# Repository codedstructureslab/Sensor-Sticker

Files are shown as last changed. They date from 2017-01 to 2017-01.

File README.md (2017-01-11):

# Sensor-Sticker

Minimal hardware for distributed sensing in aircraft, etc.

## Version

**Version 0:** 
* Minimal sensor size, irregular boards
* Ordered 2016-12-30

**Version 1:** 
* Constant sensor button size
* (TODO) Ensure that distance between connector edge and sensor centerpoint is 1.7 mm
* (TODO) Redo jtag pinout for Atmel ICE programmer
* Redo DSP310 Pinout to make assembly clearer

**Version 2:**
* ATSAMD11 Output?

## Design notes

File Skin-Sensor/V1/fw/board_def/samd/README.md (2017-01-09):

# Arduino Core for SAMD21 (E variant) CPU

This repository containts the source code and configuration files of the Arduino Core
for Atmel's SAMD21 (E variant) processor, which is used on the skin sensor boards.

## Installation on Arduino IDE

First, you should have Arduino > 1.6

To satisfy the dependencies, just open the "Boards Manager" and install the package called:

"Arduino SAMD Boards (32-bit ARM Cortex-M0+)"

Then drag this folder (`board_def`) to the `hardware` folder in the sketch directory of your Arduino installation (or make a symlink). Restart Arduino and you should see the board `Sensor-Sticker V1` listed. Select this board and upload the sketch `Skin-Sensor-AIAA`.

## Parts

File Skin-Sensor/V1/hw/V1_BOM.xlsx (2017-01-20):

Reference Designator | Quantity | Description/Value | Manufacturer Part Number (MPN)
C1,C2,C5,C6,C24,C25 | 6 | 0402 Cer Cap 1uF | C1005X5R1V105K050BC
C7,C8 | 2 | 0402 Cer Cap 22pF | CBR04C220F5GAC
C4,C9 | 2 | Wm1389 Plug (10) | 5034801000
C3,C20,C21,C23,C28,C40,C41 | 7 | 0402 Cer Cap 100nF | GRM155R71C104KA88J
C19 | 1 | 0402 Cer Cap 10uF | CL05A106MP8NUB8
C22 | 1 | 0402 Cer Cap 10nF | GRM155R71H103KA88D
C26,C27 | 2 | 0402 Cer Cap 0.47uF | C1005X5R1E474K050BB
R1 | 1 | 0402 Res 330 | RC0402JR-07330RL
R2,R3,R8,R9,R10,R11,R12,R13 | 8 | 0402 Res 10k | RC0402JR-0710KL
R14 | 1 | 0402 Res 100k | RC0402JR-07100KL
D1 | 1 | 0402 LED | LNJ247W82RA
D2 | 1 | RGB LED Common Cathode | XZM2CRKM2DGFBB45SCCB
C15,C30,C31,C32,C33,C37,C38,C39 | 8 | WM1386 Plug | 5034800400
C16,C17,C18 | 3 | WM1387 Plug | 5034800600
SW1,SW2 | 2 | Switch | TL3700AF100QG
J1 | 1 | 5x2 Header JTAG 0.05" | 20021121-00010C4LF
U1 | 1 | ADP7102 3.3V Reg | ADP7102ACPZ-3.3-R7
U2 | 1 | ATSAMD21E18A uP | ATSAMD21E18A-MFT
U3 | 1 | USBMICRO | 10104110-0001LF
U4 | 1 | LSM9DS1 IMU | LSM9DS1TR
U5 | 1 | LP5521YQ LED Driver | LP5521YQ/NOPB
U6,U7 | 2 | DPS310 Pressure Sensor | DPS310XTSA1
X1 | 1 | 32.768kHz Crystal | ABS06-32.768KHZ-1-T

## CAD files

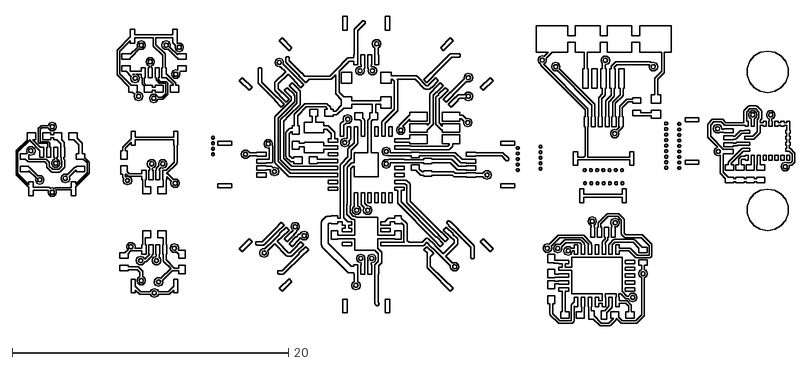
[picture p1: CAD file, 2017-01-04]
Skin-Sensor/V1/hw/CAD/DXF_OUT/Skin_Sensor_Modular_Min_BoardSize-F.Cu.dxf
56.4 x 22.4

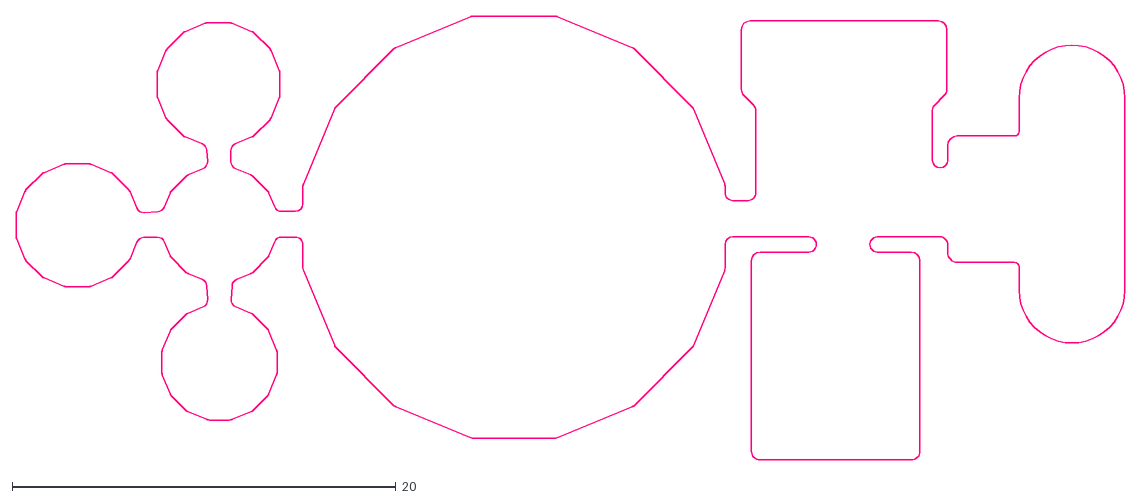
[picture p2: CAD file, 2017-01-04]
Skin-Sensor/V1/hw/CAD/Skin_Sensor_Modular_Board_Edge_Buttons.dxf
57.8 x 23.1

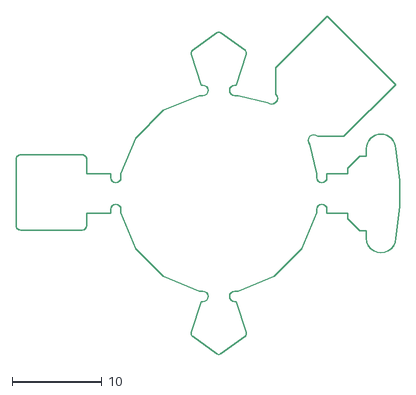
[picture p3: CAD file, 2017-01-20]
Skin-Sensor/V1/hw/DXF_OUT/Skin_Sensor_Outline_V1.dxf
42.8 x 37.8

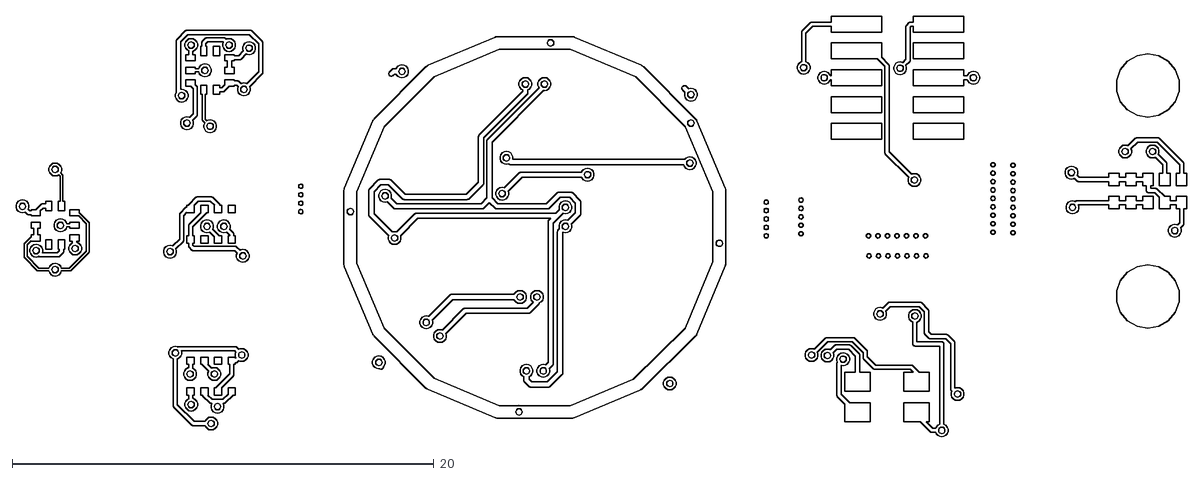
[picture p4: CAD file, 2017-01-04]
Skin-Sensor/V1/hw/CAD/DXF_OUT/Skin_Sensor_Modular_Min_BoardSize-B.Cu.dxf
55.5 x 20.0

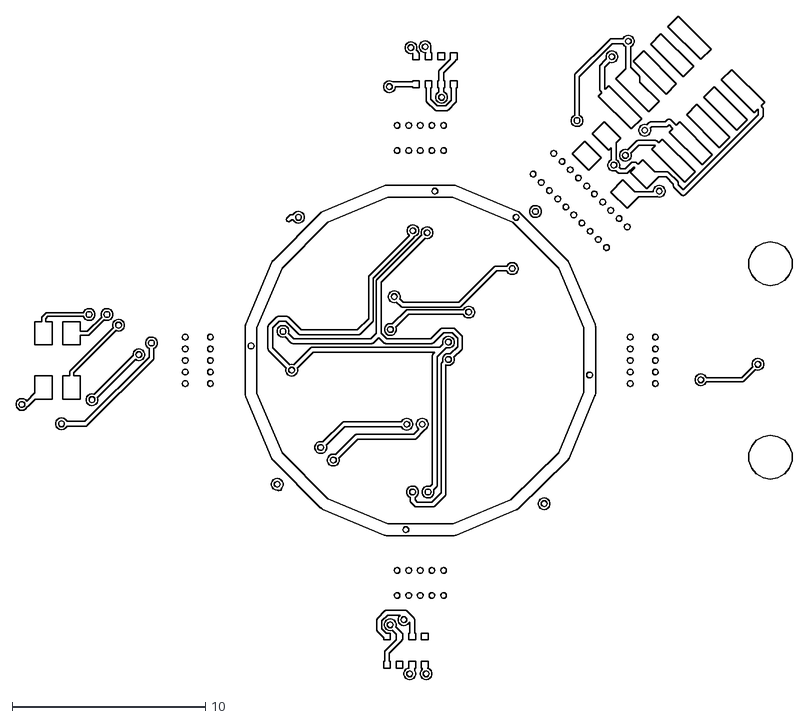
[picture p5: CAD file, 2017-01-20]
Skin-Sensor/V1/hw/DXF_OUT/Skin-Sensor-V1-B.Cu.dxf
40.1 x 34.3

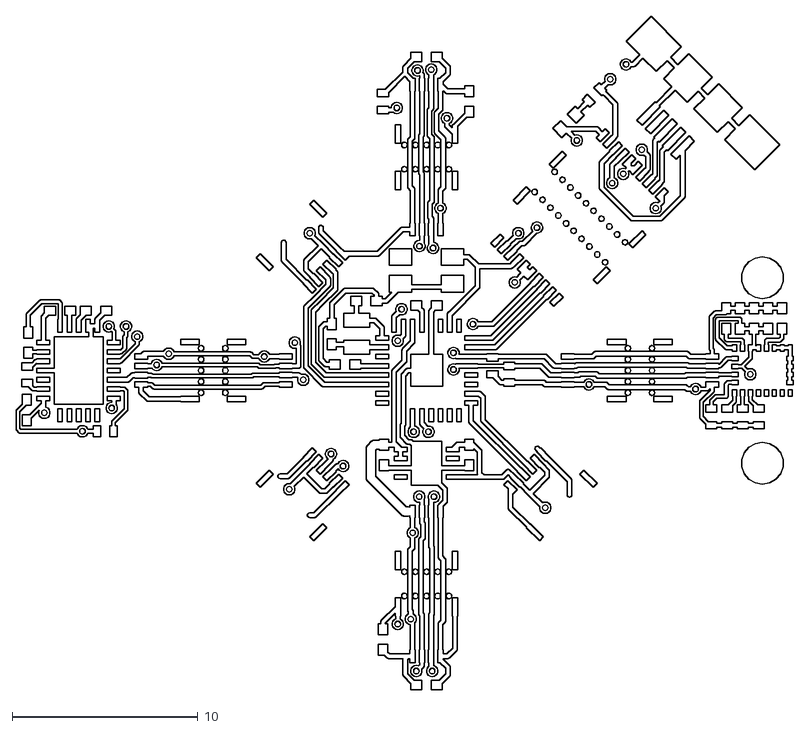
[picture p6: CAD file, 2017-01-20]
Skin-Sensor/V1/hw/DXF_OUT/Skin-Sensor-V1-F.Cu.dxf
41.9 x 36.3

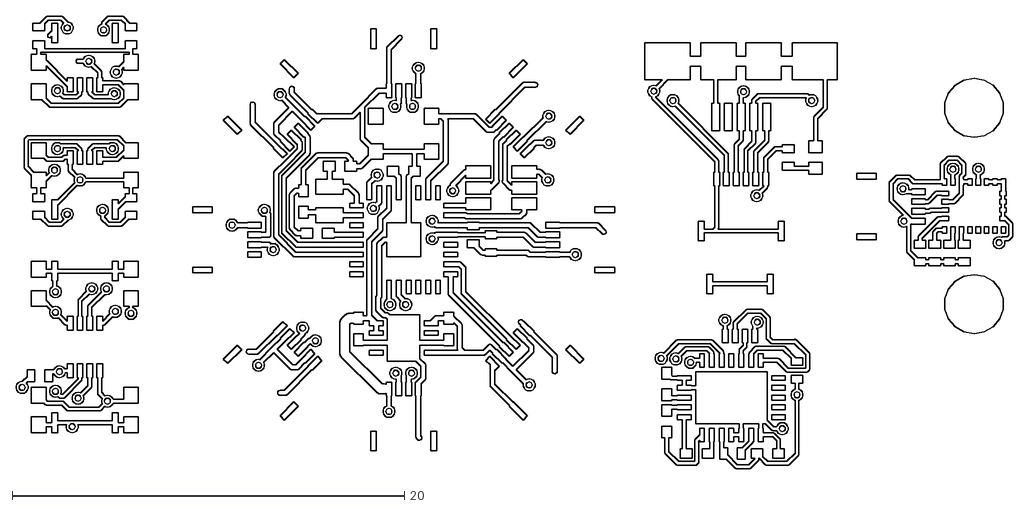
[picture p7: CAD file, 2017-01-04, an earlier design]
Skin-Sensor/V0/CAD/DXF_OUT/Skin_Sensor_Modular-F.Cu.dxf
50.8 x 23.1

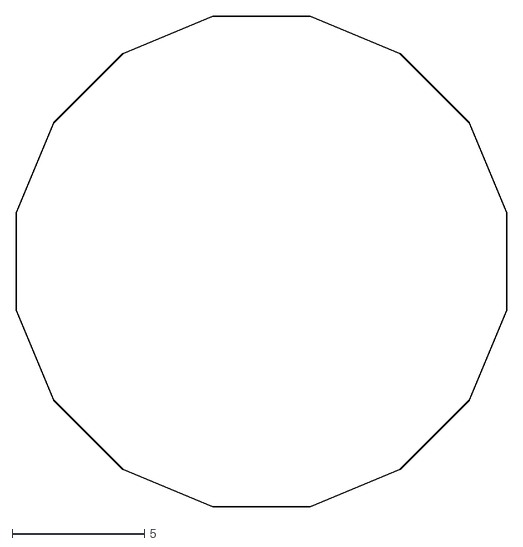
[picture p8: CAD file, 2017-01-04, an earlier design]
Skin-Sensor/V0/CAD/DXF_OUT/SSM_CopperBorderInner.dxf
18.5 x 18.5

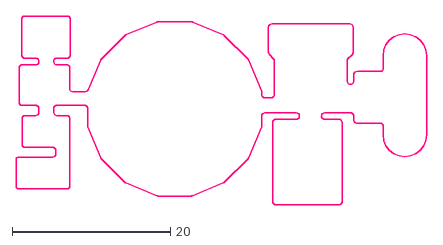
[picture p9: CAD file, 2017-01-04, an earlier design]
Skin-Sensor/V0/CAD/Skin_Sensor_Modular_Board_Edge.dxf
51.8 x 23.9

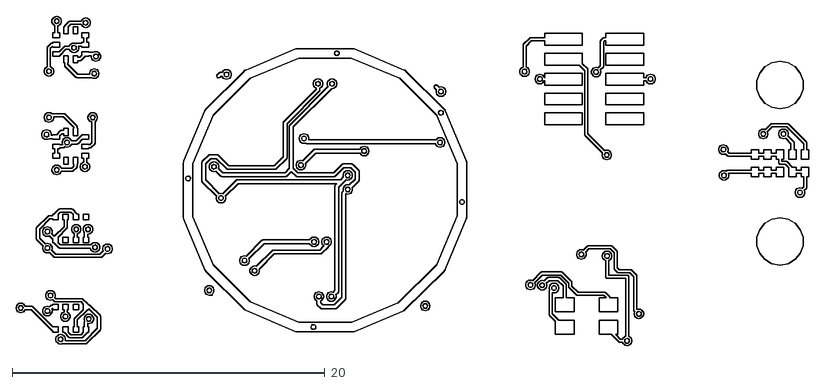
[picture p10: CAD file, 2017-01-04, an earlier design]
Skin-Sensor/V0/CAD/DXF_OUT/Skin_Sensor_Modular-B.Cu.dxf
50.7 x 21.0

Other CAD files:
Skin-Sensor/V0/CAD/Skin_Sensor_Modular_explanatory_drawing.dwg
Skin-Sensor/V0/CAD/DXF_OUT/Skin_Sensor_Modular-B.SilkS.dxf
Skin-Sensor/V0/CAD/DXF_OUT/Skin_Sensor_Modular-F.SilkS.dxf
Skin-Sensor/V0/CAD/Skin_Sensor_Modular_Board_Edge.3dm
Skin-Sensor/V1/hw/CAD/DXF_OUT/Skin_Sensor_Modular_Min_BoardSize-B.SilkS.dxf
Skin-Sensor/V1/hw/CAD/DXF_OUT/Skin_Sensor_Modular_Min_BoardSize-F.SilkS.dxf

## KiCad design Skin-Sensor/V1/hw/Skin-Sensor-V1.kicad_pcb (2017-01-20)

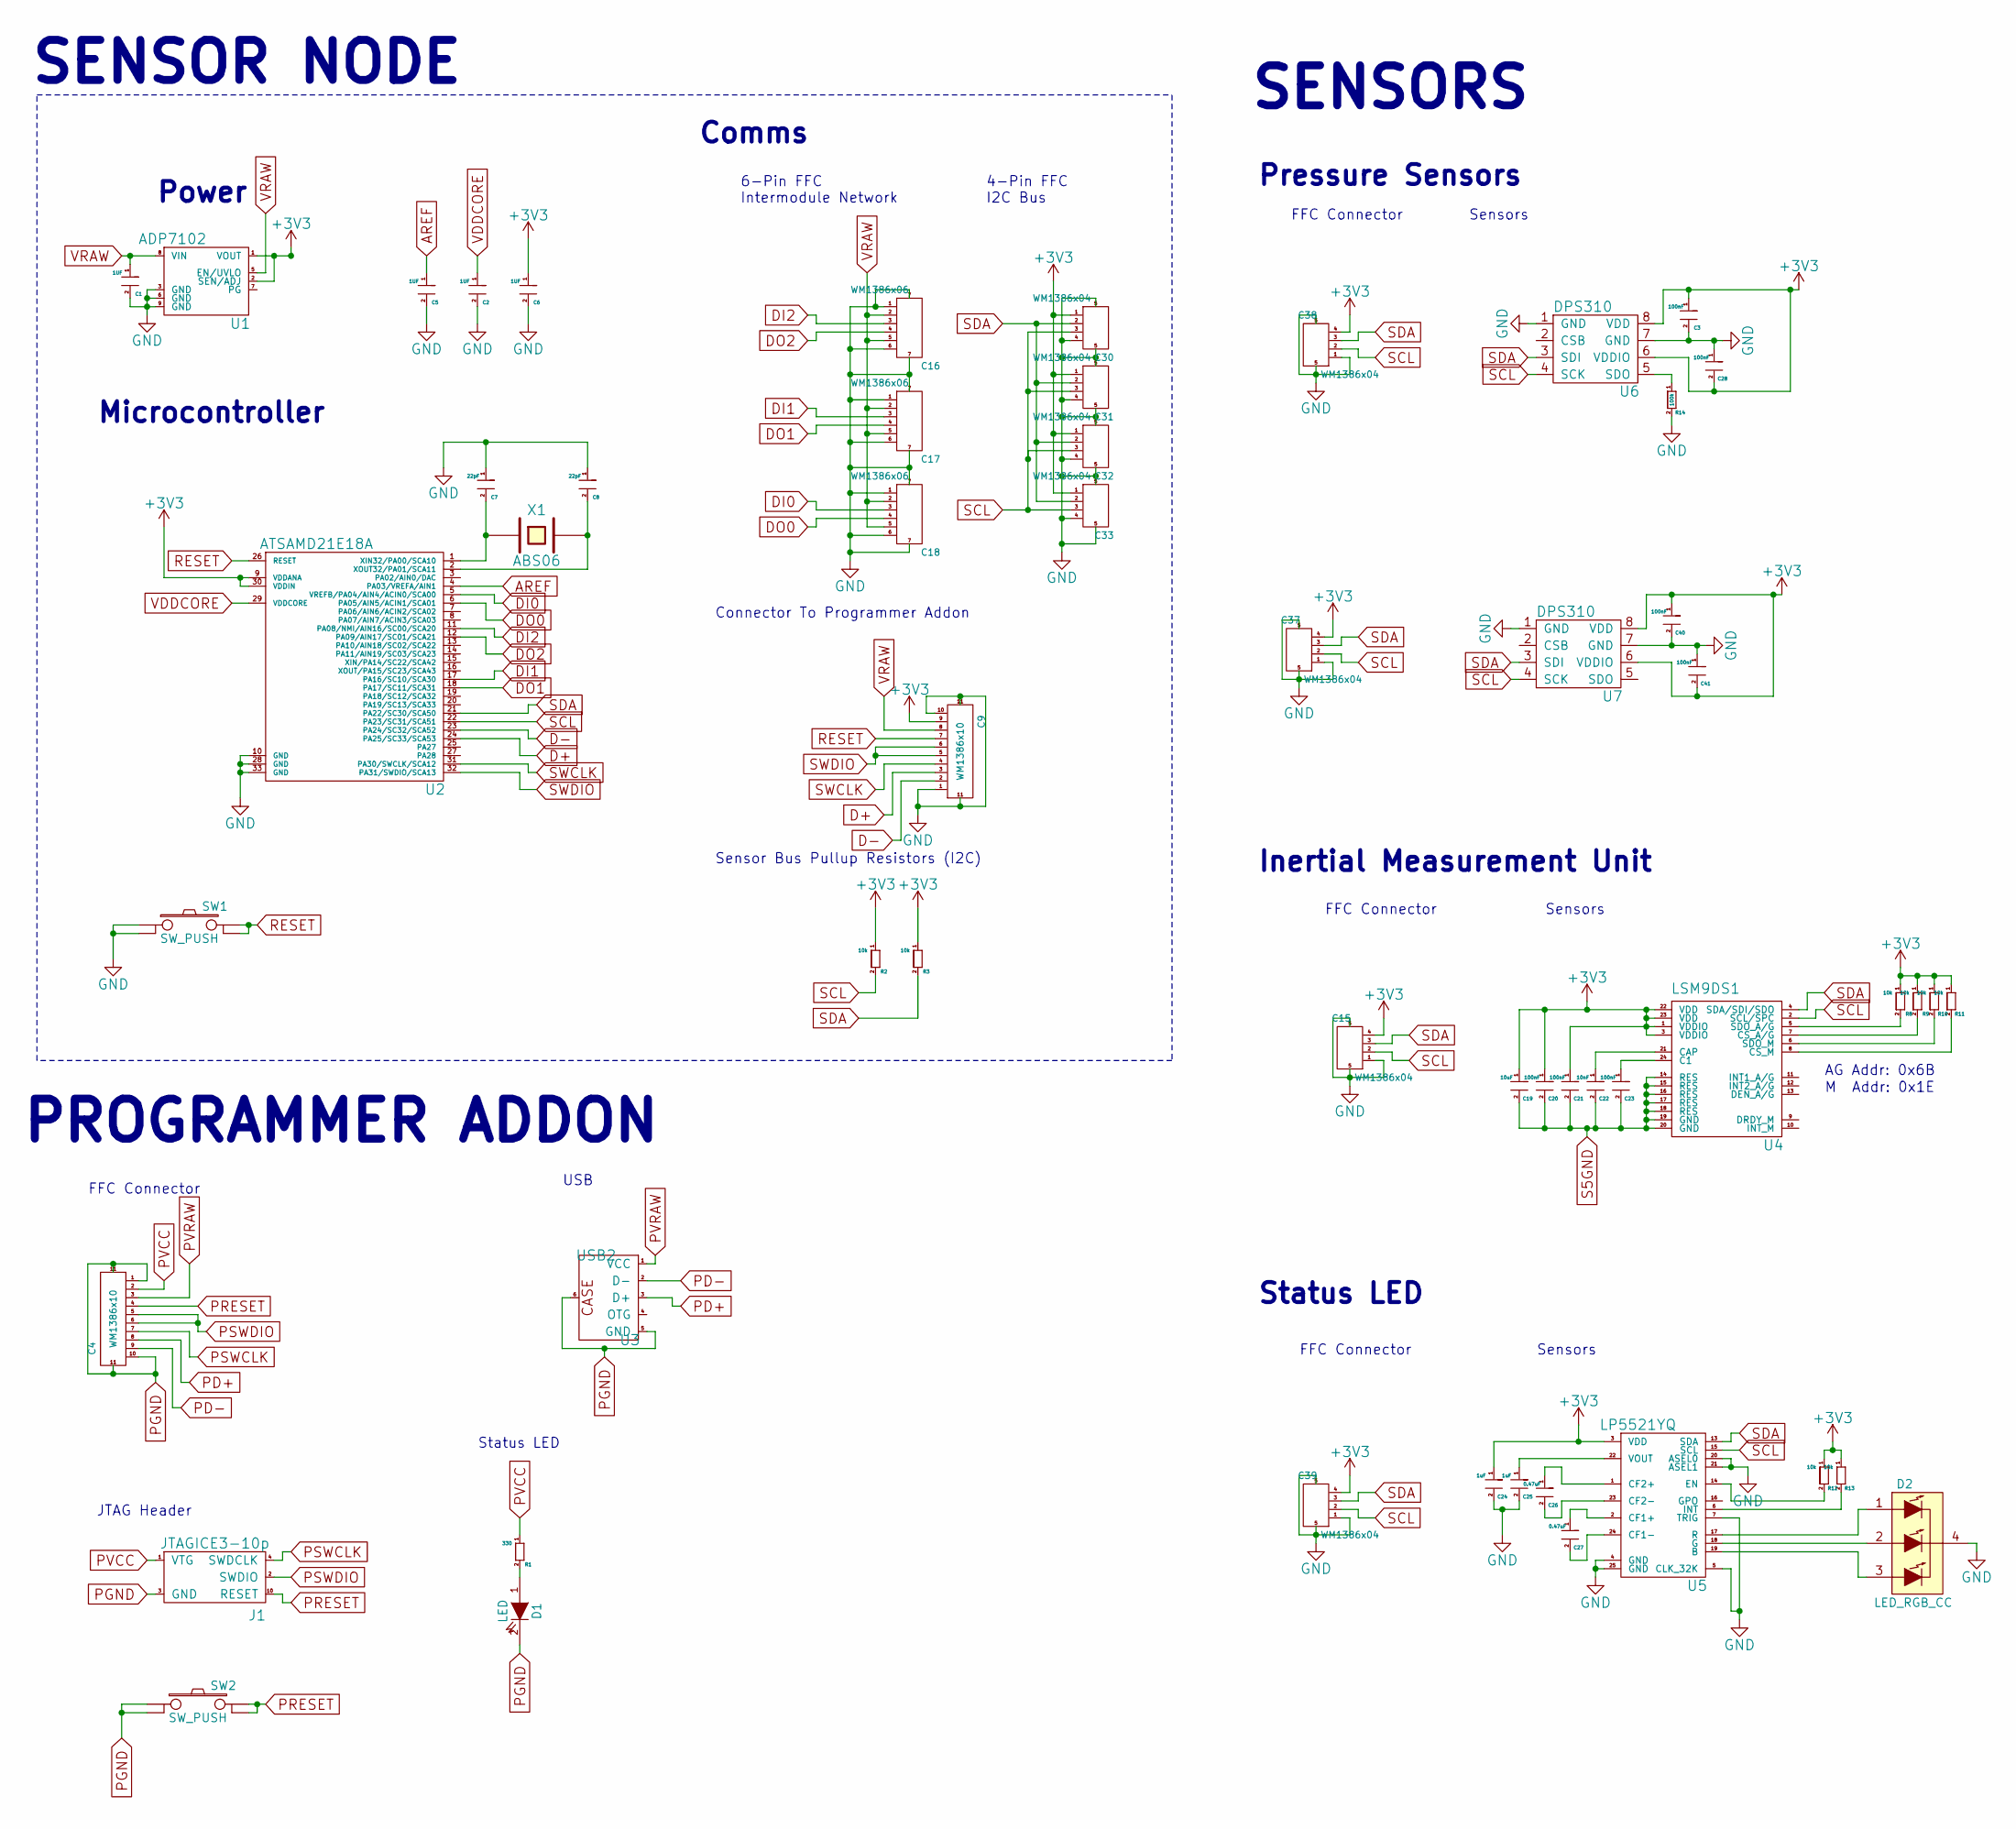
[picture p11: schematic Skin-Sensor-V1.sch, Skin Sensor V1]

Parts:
C1, C2, C5, C6: 1UF; C_0402
C3, C20, C21, C23, C28, C40, C41: 100nF; C_0402
C4, C9: WM1386x10; WM1387x10-REC
C7, C8: 22pF; C_0402
C15, C30, C31, C32, C33, C37, C38, C39: WM1386x04; WM1386x04-REC
C16, C17, C18: WM1386x06; WM1387x06-REC
C19: 10uF; C_0402
C22: 10nF; C_0402
C24, C25: 1uF; C_0402
C26, C27: 0.47uF; C_0402
D1: LED; LED_0402
D2: LED_RGB_CC; 4-PLCC
J1: JTAGICE3-10p
R1: 330; R_0402
R2, R3, R8, R9, R10, R11, R12, R13: 10k; R_0402
R14: 100k; R_0402
SW1, SW2: SW_PUSH; 4-PLCC
U1: ADP7102; DFN-8-1EP_3x3mm_Pitch0.5mm
U2: ATSAMD21E18A; QFN-32-1EP_5x5mm_Pitch0.5mm
U3: USB2; USBMICRO-10104110
U4: LSM9DS1
U5: LP5521YQ; QFN-24-1EP_4x5mm_Pitch0.5mm
U6, U7: DPS310; 8-LGA
X1: ABS06

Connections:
+3V3: C3.1, C6.1, C9.9, C15.4, C19.1, C20.1, C21.1, C24.1, C28.2, C30.1, C31.1, C32.1, C33.1, C37.4, C38.4, C39.4, C40.1, C41.2, R2.1, R3.1, R8.1, R9.1, R10.1, R11.1, R12.1, R13.1, U1.1 (VOUT), U1.2 (SEN/ADJ), U2.9 (VDDANA), U2.30 (VDDIN), U4.1 (VDDIO), U4.3 (VDDIO), U4.22 (VDD), U4.23 (VDD), U5.3 (VDD), U6.6 (VDDIO), U6.8 (VDD), U7.6 (VDDIO), U7.8 (VDD)
AREF: C5.1, U2.4 (PA03/VREFA/AIN1)
D+: C9.3, U2.24 (PA25/SC33/SCA53)
D-: C9.2, U2.23 (PA24/SC32/SCA52)
DI0: C18.3, U2.5 (VREFB/PA04/AIN4/ACIN0/SCA00)
DI1: C17.3, U2.17 (PA16/SC10/SCA30)
DI2: C16.3, U2.11 (PA08/NMI/AIN16/SC00/SCA20)
DO0: C18.4, U2.6 (PA05/AIN5/ACIN1/SCA01)
DO1: C17.4, U2.18 (PA17/SC11/SCA31)
DO2: C16.4, U2.12 (PA09/AIN17/SC01/SCA21)
GND: C1.2, C2.2, C3.2, C5.2, C6.2, C7.1, C8.1, C9.1, C9.10, C9.11, C15.1, C15.5, C16.1, C16.6, C16.7, C17.1, C17.6, C17.7, C18.1, C18.6, C18.7, C24.2, C25.2, C28.1, C30.4, C30.5, C31.4, C31.5, C32.4, C32.5, C33.4, C33.5, C37.1, C37.5, C38.1, C38.5, C39.1, C39.5, C40.2, C41.1, D2.4 (COMMON_CATHODE), R14.2, SW1.1, SW1.2, U1.3 (GND), U1.6 (GND), U1.9 (GND), U2.10 (GND), U2.28 (GND), U2.33 (GND), U5.4 (GND), U5.5 (CLK_32K), U5.7 (TRIG), U5.20 (ASEL0), U5.21 (ASEL1), U5.25 (GND), U6.1 (GND), U6.7 (GND), U7.1 (GND), U7.7 (GND)
unnamed: C7.2, U2.1 (XIN32/PA00/SCA10), X1.1
unnamed: C8.2, U2.2 (XOUT32/PA01/SCA11), X1.2
unnamed: C22.1, U4.21 (CAP)
unnamed: C23.1, U4.24 (C1)
unnamed: C25.1, U5.22 (VOUT)
unnamed: C26.1, U5.1 (CF2+)
unnamed: C26.2, U5.23 (CF2-)
unnamed: C27.1, U5.2 (CF1+)
unnamed: C27.2, U5.24 (CF1-)
unnamed: D1.1 (A), R1.2
unnamed: D2.1 (RED_ANODE), U5.17 (R)
unnamed: D2.2 (GREEN_ANODE), U5.18 (G)
unnamed: D2.3 (BLUE_ANODE), U5.19 (B)
unnamed: R8.2, U4.5 (SDO_A/G)
unnamed: R9.2, U4.7 (CS_A/G)
unnamed: R10.2, U4.6 (SDO_M)
unnamed: R11.2, U4.8 (CS_M)
unnamed: R12.2, U5.14 (EN)
unnamed: R13.2, U5.6 (INT)
unnamed: R14.1, U6.5 (SDO)
PD+: C4.8, U3.3 (D+)
PD-: C4.9, U3.2 (D-)
PGND: C4.1, C4.10, C4.11, D1.2 (K), J1.3 (GND), SW2.1, SW2.2, U3.5 (GND), U3.6
PRESET: C4.4, J1.10 (RESET), SW2.3, SW2.4
PSWCLK: C4.7, J1.4 (SWDCLK)
PSWDIO: C4.5, C4.6, J1.2 (SWDIO)
PVCC: C4.2, J1.1 (VTG), R1.1
PVRAW: C4.3, U3.1 (VCC)
RESET: C9.7, SW1.3, SW1.4, U2.26 (RESET)
S5GND: C19.2, C20.2, C21.2, C22.2, C23.2, U4.14 (RES), U4.15 (RES), U4.16 (RES), U4.17 (RES), U4.18 (RES), U4.19 (GND), U4.20 (GND)
SCL: C15.2, C30.3, C31.3, C32.3, C33.3, C37.2, C38.2, C39.2, R2.2, U2.22 (PA23/SC31/SCA51), U4.2 (SCL/SPC), U5.15 (SCL), U6.4 (SCK), U7.4 (SCK)
SDA: C15.3, C30.2, C31.2, C32.2, C33.2, C37.3, C38.3, C39.3, R3.2, U2.21 (PA22/SC30/SCA50), U4.4 (SDA/SDI/SDO), U5.13 (SDA), U6.3 (SDI), U7.3 (SDI)
SWCLK: C9.4, U2.31 (PA30/SWCLK/SCA12)
SWDIO: C9.5, C9.6, U2.32 (PA31/SWDIO/SCA13)
VDDCORE: C2.1, U2.29 (VDDCORE)
VRAW: C1.1, C9.8, C16.2, C16.5, C17.2, C17.5, C18.2, C18.5, U1.5 (EN/UVLO), U1.8 (VIN)

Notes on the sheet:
Power
Microcontroller
Comms
SENSORS
Status LED
AG Addr: 0x6B
M Addr: 0x1E
SENSOR NODE
PROGRAMMER ADDON
6-Pin FFC Intermodule Network
Sensor Bus Pullup Resistors (I2C)
Connector To Programmer Addon
JTAG Header
USB
FFC Connector
Sensors
Pressure Sensors
Inertial Measurement Unit
4-Pin FFC I2C Bus

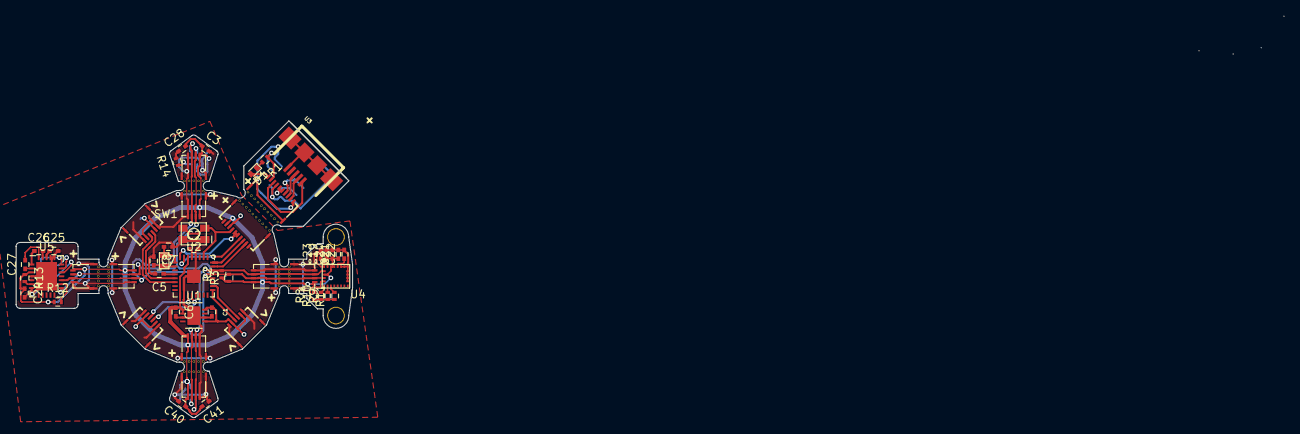
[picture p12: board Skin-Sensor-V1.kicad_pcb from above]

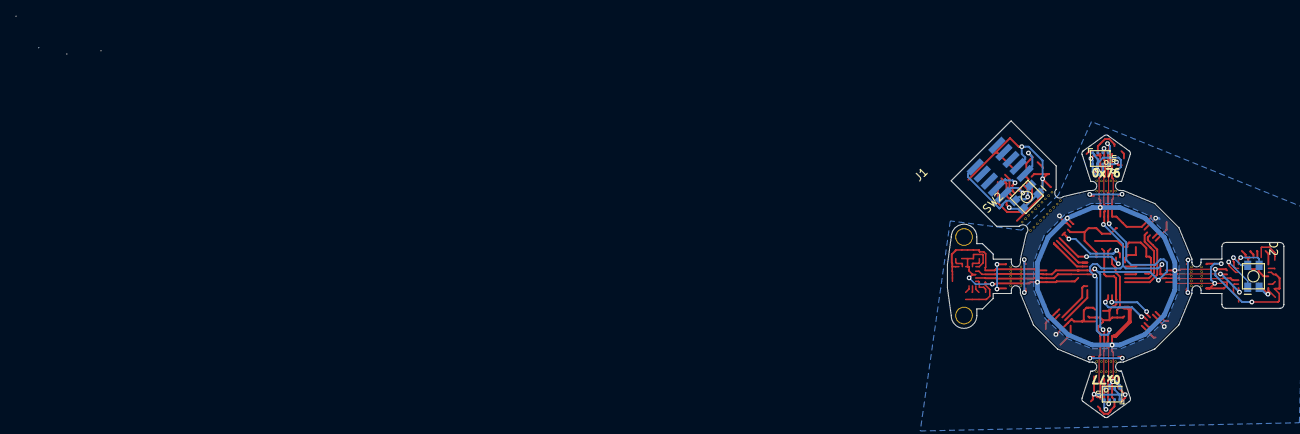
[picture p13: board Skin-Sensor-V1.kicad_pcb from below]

Board: 2 copper layers, 42.8 x 37.8 mm, 55 parts (5 on the bottom side), 47 nets.

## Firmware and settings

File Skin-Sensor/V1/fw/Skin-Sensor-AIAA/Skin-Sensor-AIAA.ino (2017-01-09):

#include "APA.h"
#include <lp5521.h>
#include <LPS.h>


Lp5521 ledChip(0x32);
LPS ps1;
LPS ps2;

uint32_t curtime;
uint32_t pressure_sensor_update_time, led_update_time,verbose_time;
uint32_t calibration_time = 30000;

uint32_t pressure_sensor_update_interval = 50;
uint32_t led_update_interval = 50;
uint32_t verbose_interval = 50;

uint8_t rainbowtime = 0;

float raw_pa_factor = 1.0/4096.0;

uint8_t num_samples = 50;

float num_sample_factor = 1.0/num_samples;
float num_sample_factor_var = 1.0/(num_samples-1);

float var_threshold_factor = 30.0;

float ps1_val_cur, ps2_val_cur;
float ps1_val_avg, ps2_val_avg;
float ps1_val_var, ps2_val_var;

float ps1_baseline_pressure, ps2_baseline_pressure;
uint8_t baseline_counter = 0;

bool verbose_mode = true;
bool calibrating = true;

void setup() {
  SerialUSB.begin(9600);
  APA0.begin(9600);
  APA1.begin(9600);
  APA2.begin(9600);

  if(verbose_mode){
    delay(3000);
    Serial.println("Starting LED");
  }

  ledChip.Begin();
  
  if(verbose_mode){
    Serial.println("Enabling LED");
  }
  ledChip.Enable();

  if(verbose_mode){
    SerialUSB.println("Initializing Pressure Sensor 1");
  }
  
  ps1.init(LPS::deviceType::device_25H,LPS::sa0State::sa0_low);

  if(verbose_mode){
    SerialUSB.println("Initializing Pressure Sensor 2");
  }
  ps2.init(LPS::deviceType::device_25H,LPS::sa0State::sa0_high);

  if(verbose_mode){
    SerialUSB.println("Enabling Pressure Sensor 1");
  }
  ps1.enableDefault();
  
  if(verbose_mode){
    SerialUSB.println("Enabling Pressure Sensor 2");
  }
  ps2.enableDefault();

  curtime = 0;
  pressure_sensor_update_time = 0;
  led_update_time = 0;
  verbose_time = 0;
  
  ps1_val_avg = raw_pa_factor*ps1.readPressureRaw();
  ps2_val_avg = raw_pa_factor*ps2.readPressureRaw();

  ps1_val_var = 0;
  ps2_val_var = 0;

  delay(500);
}

void loop() {
  curtime = millis();
  
  if(curtime - pressure_sensor_update_time > pressure_sensor_update_interval){
    pressure_sensor_update_time = curtime;
    updatePressure();
  }

  if(curtime - led_update_time > led_update_interval){
    led_update_time = curtime;
    if(calibrating)
      rainbow();
    else
      updateLED();
  }
  if(calibrating && curtime > calibration_time){
    calibrating = false;
  }
  if(verbose_mode && curtime - verbose_time > verbose_interval){
    verbose_time = curtime; 
    SerialUSB.print(ps1_val_cur);
    SerialUSB.print("\t");
    ///*
    SerialUSB.print(ps1_val_avg + ps1_val_var*num_sample_factor_var*var_threshold_factor);
    SerialUSB.print("\t");
    SerialUSB.print(ps1_val_avg - ps1_val_var*num_sample_factor_var*var_threshold_factor);
    SerialUSB.print("\t"); 
    //*/
    SerialUSB.print(ps2_val_cur);
    ///*
    SerialUSB.print("\t");
    SerialUSB.print(ps2_val_avg + ps2_val_var*num_sample_factor_var*var_threshold_factor);
    SerialUSB.print("\t");
    SerialUSB.println(ps2_val_avg - ps2_val_var*num_sample_factor_var*var_threshold_factor);
    //*/
  }
}

void updatePressure(){
  ps1_val_cur = raw_pa_factor*ps1.readPressureRaw();
  ps2_val_cur = raw_pa_factor*ps2.readPressureRaw();
  
  if(calibrating){
    ps1_val_var = ps1_val_var + (ps1_val_cur-ps1_val_avg)*(ps1_val_cur-(ps1_val_avg+num_sample_factor*(ps1_val_cur-ps1_val_avg)));
    ps1_val_avg = ps1_val_avg+num_sample_factor*(ps1_val_cur-ps1_val_avg);
    ps2_val_var = ps2_val_var + (ps2_val_cur-ps2_val_avg)*(ps2_val_cur-(ps2_val_avg+num_sample_factor*(ps2_val_cur-ps2_val_avg)));
    ps2_val_avg = ps2_val_avg+num_sample_factor*(ps2_val_cur-ps2_val_avg);
    if(ps1_val_cur > 1260)
      ps1_val_cur = 1260;
    if(ps2_val_cur > 1260)
      ps2_val_cur = 1260;
    if(ps1_val_avg > 1260 || ps1_val_avg < 960)
      ps1_val_avg = ps1_val_cur;
    if(ps2_val_avg > 1260 || ps2_val_avg < 960)
      ps2_val_avg = ps2_val_cur;
    if(ps2_val_var > 100)
      ps2_val_var = 0;  
    if(ps1_val_var > 100)
      ps1_val_var = 0;
  }
  else{
    if(abs(ps1_val_cur-ps1_val_avg) > 3.0*ps1_val_var*num_sample_factor_var){
      ps1_val_avg = ps1_val_avg + (ps1_val_cur-ps1_val_avg)*num_sample_factor*0.01;
    }
    if(abs(ps2_val_cur-ps2_val_avg) > 3.0*ps2_val_var*num_sample_factor_var){
      ps2_val_avg = ps2_val_avg + (ps2_val_cur-ps2_val_avg)*num_sample_factor*0.01;
    }
  }
}

void updateLED(){
  uint8_t rv = 0;
  uint8_t gv = 0;
  uint8_t bv = 0;
  
  if(abs(ps1_val_cur-ps1_val_avg) > var_threshold_factor*ps1_val_var*num_sample_factor_var){
    rv = 127;
  }

  if(abs(ps2_val_cur-ps2_val_avg) > var_threshold_factor*ps2_val_var*num_sample_factor_var){
    bv = 127;
  }

  ledChip.SetChannelPWM(0,rv); 
  ledChip.SetChannelPWM(1,bv);
  ledChip.SetChannelPWM(2,gv);
}

char* readMessage(APA_Node *node){
  if(node->getId() == 0){
    
  }
}

void rainbow() {
  rainbowtime = (rainbowtime + 1)%255;
  uint32_t color = Wheel(rainbowtime&255);
  ledChip.SetChannelPWM(0, (color >> 16) & 0xFF);
  ledChip.SetChannelPWM(1, (color >> 8) & 0xFF);
  ledChip.SetChannelPWM(2, color & 0xFF);
}

// Input a value 0 to 255 to get a color value.
// The colours are a transition r - g - b - back to r.
uint32_t Wheel(byte WheelPos) {
  WheelPos = 255 - WheelPos;
  if(WheelPos < 85) {
    return (uint32_t)(((255 - WheelPos * 3)<<16) | (WheelPos * 3));
  }
  if(WheelPos < 170) {
    WheelPos -= 85;
    return (uint32_t)(((WheelPos * 3)<<8) | (255 - WheelPos * 3));
  }
  WheelPos -= 170;
  return (uint32_t)(((WheelPos * 3)<<16) | ((255 - WheelPos * 3)<<8));
}

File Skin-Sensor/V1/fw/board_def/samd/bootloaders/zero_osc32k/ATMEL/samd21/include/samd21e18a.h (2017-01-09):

/**
 * \file
 *
 * \brief Header file for SAMD21E18A
 *
 * Copyright (c) 2014 Atmel Corporation. All rights reserved.
 *
 * \asf_license_start
 *
 * \page License
 *
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
 * 3. The name of Atmel may not be used to endorse or promote products derived
 *    from this software without specific prior written permission.
 *
 * 4. This software may only be redistributed and used in connection with an
 *    Atmel microcontroller product.
 *
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
 * \asf_license_stop
 *
 */

#ifndef _SAMD21E18A_
#define _SAMD21E18A_

/**
 * \ingroup SAMD21_definitions
 * \addtogroup SAMD21E18A_definitions SAMD21E18A definitions
 * This file defines all structures and symbols for SAMD21E18A:
 *   - registers and bitfields
 *   - peripheral base address
 *   - peripheral ID
 *   - PIO definitions
*/
/*@{*/

#ifdef __cplusplus
 extern "C" {
#endif

#if !(defined(__ASSEMBLY__) || defined(__IAR_SYSTEMS_ASM__))
#include <stdint.h>
#ifndef __cplusplus
typedef volatile const uint32_t RoReg;   /**< Read only 32-bit register (volatile const unsigned int) */
typedef volatile const uint16_t RoReg16; /**< Read only 16-bit register (volatile const unsigned int) */
typedef volatile const uint8_t  RoReg8;  /**< Read only  8-bit register (volatile const unsigned int) */
#else
typedef volatile       uint32_t RoReg;   /**< Read only 32-bit register (volatile const unsigned int) */
typedef volatile       uint16_t RoReg16; /**< Read only 16-bit register (volatile const unsigned int) */
typedef volatile       uint8_t  RoReg8;  /**< Read only  8-bit register (volatile const unsigned int) */
#endif
typedef volatile       uint32_t WoReg;   /**< Write only 32-bit register (volatile unsigned int) */
typedef volatile       uint16_t WoReg16; /**< Write only 16-bit register (volatile unsigned int) */
typedef volatile       uint32_t WoReg8;  /**< Write only  8-bit register (volatile unsigned int) */
typedef volatile       uint32_t RwReg;   /**< Read-Write 32-bit register (volatile unsigned int) */
typedef volatile       uint16_t RwReg16; /**< Read-Write 16-bit register (volatile unsigned int) */
typedef volatile       uint8_t  RwReg8;  /**< Read-Write  8-bit register (volatile unsigned int) */
#define CAST(type, value) ((type *)(value))
#define REG_ACCESS(type, address) (*(type*)(address)) /**< C code: Register value */
#else
#define CAST(type, value) (value)
#define REG_ACCESS(type, address) (address) /**< Assembly code: Register address */
#endif

/* ************************************************************************** */
/**  CMSIS DEFINITIONS FOR SAMD21E18A */
/* ************************************************************************** */
/** \defgroup SAMD21E18A_cmsis CMSIS Definitions */
/*@{*/

/** Interrupt Number Definition */
typedef enum IRQn
{
  /******  Cortex-M0+ Processor Exceptions Numbers *******************************/
  NonMaskableInt_IRQn      = -14, /**<  2 Non Maskable Interrupt                 */
  HardFault_IRQn           = -13, /**<  3 Cortex-M0+ Hard Fault Interrupt        */
  SVCall_IRQn              = -5,  /**< 11 Cortex-M0+ SV Call Interrupt           */
  PendSV_IRQn              = -2,  /**< 14 Cortex-M0+ Pend SV Interrupt           */
  SysTick_IRQn             = -1,  /**< 15 Cortex-M0+ System Tick Interrupt       */
  /******  SAMD21E18A-specific Interrupt Numbers ***********************/
  PM_IRQn                  =  0, /**<  0 SAMD21E18A Power Manager (PM) */
  SYSCTRL_IRQn             =  1, /**<  1 SAMD21E18A System Control (SYSCTRL) */
  WDT_IRQn                 =  2, /**<  2 SAMD21E18A Watchdog Timer (WDT) */
  RTC_IRQn                 =  3, /**<  3 SAMD21E18A Real-Time Counter (RTC) */
  EIC_IRQn                 =  4, /**<  4 SAMD21E18A External Interrupt Controller (EIC) */
  NVMCTRL_IRQn             =  5, /**<  5 SAMD21E18A Non-Volatile Memory Controller (NVMCTRL) */
  DMAC_IRQn                =  6, /**<  6 SAMD21E18A Direct Memory Access Controller (DMAC) */
  USB_IRQn                 =  7, /**<  7 SAMD21E18A Universal Serial Bus (USB) */
  EVSYS_IRQn               =  8, /**<  8 SAMD21E18A Event System Interface (EVSYS) */
  SERCOM0_IRQn             =  9, /**<  9 SAMD21E18A Serial Communication Interface 0 (SERCOM0) */
  SERCOM1_IRQn             = 10, /**< 10 SAMD21E18A Serial Communication Interface 1 (SERCOM1) */
  SERCOM2_IRQn             = 11, /**< 11 SAMD21E18A Serial Communication Interface 2 (SERCOM2) */
  SERCOM3_IRQn             = 12, /**< 12 SAMD21E18A Serial Communication Interface 3 (SERCOM3) */
  SERCOM4_IRQn             = 13, /**< 13 SAMD21G18A Serial Communication Interface 4 (SERCOM4) */
  SERCOM5_IRQn             = 14, /**< 14 SAMD21G18A Serial Communication Interface 5 (SERCOM5) */
  TCC0_IRQn                = 15, /**< 15 SAMD21E18A Timer Counter Control 0 (TCC0) */
  TCC1_IRQn                = 16, /**< 16 SAMD21E18A Timer Counter Control 1 (TCC1) */
  TCC2_IRQn                = 17, /**< 17 SAMD21E18A Timer Counter Control 2 (TCC2) */
  TC3_IRQn                 = 18, /**< 18 SAMD21E18A Basic Timer Counter 3 (TC3) */
  TC4_IRQn                 = 19, /**< 19 SAMD21E18A Basic Timer Counter 4 (TC4) */
  TC5_IRQn                 = 20, /**< 20 SAMD21E18A Basic Timer Counter 5 (TC5) */
  ADC_IRQn                 = 23, /**< 23 SAMD21E18A Analog Digital Converter (ADC) */
  AC_IRQn                  = 24, /**< 24 SAMD21E18A Analog Comparators (AC) */
  DAC_IRQn                 = 25, /**< 25 SAMD21E18A Digital Analog Converter (DAC) */
  PTC_IRQn                 = 26, /**< 26 SAMD21E18A Peripheral Touch Controller (PTC) */
  I2S_IRQn                 = 27, /**< 27 SAMD21E18A Inter-IC Sound Interface (I2S) */

  PERIPH_COUNT_IRQn        = 28  /**< Number of peripheral IDs */
} IRQn_Type;
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

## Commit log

2017-01-04 Added V0, V1 boards
    [MK1_MODULAR_BOM.xlsx, SSM_CopperBorderInner.dxf, Skin-Sensor-V1.kicad_pcb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]
2017-01-04 Added documentation .dwg
    [Skin_Sensor_Modular_Board_Edge.3dm, Skin_Sensor_Modular_explanatory_drawing.dwg]
2017-01-09 Skin Sensor Dump
    [MK1_MODULAR_BOM.xlsx, Skin-Sensor-V1.kicad_pcb, Skin-Sensor-V1.sch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]
2017-01-20 V1 rev, in all its glory
    [MK1_MODULAR_BOM.xlsx, Skin-Sensor-V1-B.Cu.dxf, Skin-Sensor-V1-F.Cu.dxf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]
